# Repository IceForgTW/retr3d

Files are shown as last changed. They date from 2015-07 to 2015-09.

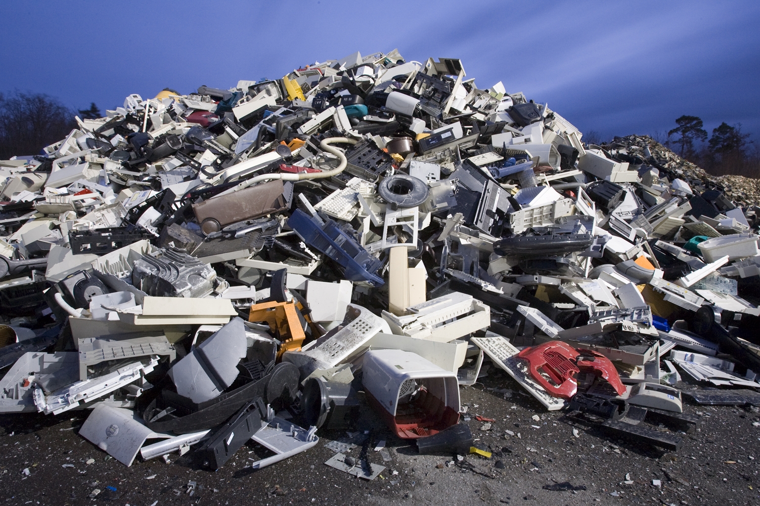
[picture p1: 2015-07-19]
img/ewaste.jpg

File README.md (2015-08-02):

## Notice
E-Waste 3D Printer is now **Retr3d**, pronounced just like "Retread." This change reflects the "Retreading" of 2D printers with a Z-Axis.
_____________

# Retr3d
In 2009, discarded TVs, computers, peripherals (including printers, scanners, fax machines) mice, keyboards, and cell phones totaled about 2.37 million short tons. Most of our e-waste ends up in landfills where toxic metals leach into the environment. This open source project aims to convert some of that e-waste into usable 3D printers. 
## Software
Retr3d uses python and FreeCAD to 3D model printable parts for the construction of more 3D printers. Through globalVars.py dimensions of procured e-waste are turned into customized 3D models. Retr3d's software depends on FreeCAD's python scripting API. FreeCAD can be found [here](http://www.freecadweb.org/wiki/index.php?title=Download "Download FreeCAD").
## Installation: Quick Version
Head over to our [latest release](https://github.com/masterperson40/retr3d/releases/latest) and download your appropriate file. Next, extract it. Hazzah! You're all done, now head over to <a href="#getting-started">Getting Started</a> to get on your way.

## Configuration
All of the customizable options can be configured [here.](https://cdn.rawgit.com/masterperson40/ewaste3Dprinter/master/config_generator/index.html) After generating your configuration file make sure to replace the original "globalVars.py file with the newly generated one.
## Getting Started
To begin creating a printer from the default options, open FreeCAD. Next, select from the menu.
Select "Macro > Macros ..."
<br />
Next, select the folder where is stored.
<br />
Click the "..." Button
Finally, select for the available options. After that, hit to create a printer.
Click makePrinter.py
<br />
If everything was installed correctly, you should now have something that looks like this:
printer
<br />
Remember, it might take a while for your printer to be modelled. Please be patient. 
## Plate
To facilitate an efficient work flow, Retr3d can interface with [Plater](https://github.com/RobotsWar/Plater) to arrange parts in an extremely efficient manner. Make sure to put the appropriate version of plater in the "plater" folder. (Eg. plater.exe, plater.app, or plater)

Plater
## Slic3r Integration
Retr3d can also interface with [Slic3r](https://github.com/alexrj/Slic3r) to slice parts automatically. After installing the dependencies, make sure to put the appropriate version of Slic3r in the "Slic3r" folder. (Eg. slic3r.exe, slic3r.app, or slic3r)

## Troubleshooting
#### AttributeError: 'module' object has no attribute 'getDocument'
This error is generated when running "makePrinter.py" directly from the command line. To fix, follow the instructions under "Getting Started" to run "makePrinter.py" as a FreeCAD macro.

#### raise Exception("getFace() error: No such face exists.")

Due to the way FreeCAD assigns faces in it's version 0.15, some users may have to downgrade to an earlier version. FreeCAD 0.14 Revision 2935 has been confirmed to work on a multitude of operating systems. Also, FreeCAD Version 0.16 Revision 5239 has also been confirmed to work.

To downgrade on Debian Linux:
```
sudo apt-get install freecad=0.13.2935-dfsg-1.1build1
```

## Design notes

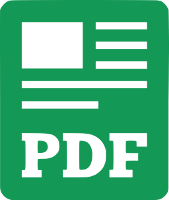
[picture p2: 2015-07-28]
img/pdf.png

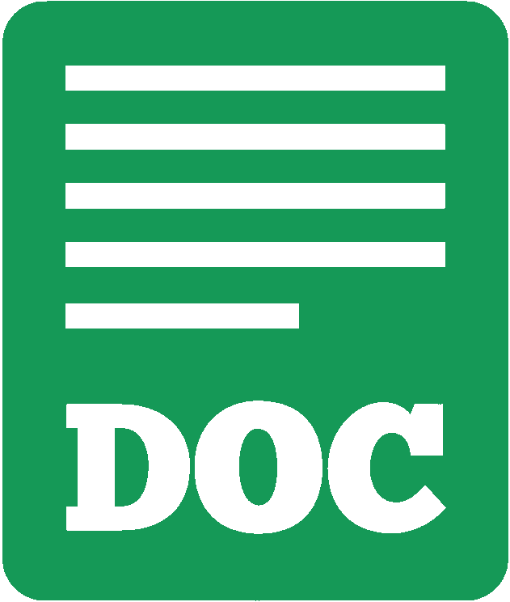
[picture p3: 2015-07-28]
img/doc.png

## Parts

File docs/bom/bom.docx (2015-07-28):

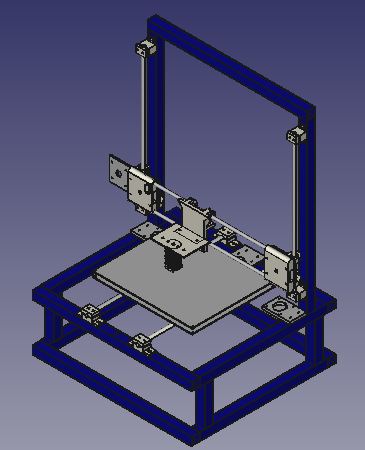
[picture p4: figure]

# Retr3d 3D Printer BOM updated 7/27/15

The materials needed to build the Retr3d 3D printer are divided into 3 categories: e-Waste components, printed parts, and purchased parts. Exact quantities of items like wire and steel tubing for the frame may vary, as all of the e-Waste printers are potentially unique.

E-Waste Components

See the E-Waste Harvesting notes for more information on how to identify, remove and group components that will work well for 3D printers. Be safe, e-waste can be dangerous!

Image | Item | Quantity | Source | Comments

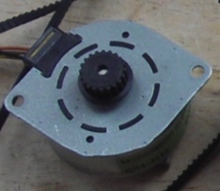
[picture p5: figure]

or | Stepper Motor, z-Axis | 2 | Paper printer, photocopier or scanner | The two motors must be the same. They can be either low-resolution “Tin Can” steppers or higher resolution hybrid steppers. No belt is needed for these motors. 4, 6,or 8 wire motors will work.
| Stepper Motor, x-Axis | 1 | Paper printer, photocopier or scanner | This must be a high-resolution hybrid stepper. If possible, it should be salvaged with a matching belt, pulley, and idler. 4, 6,or 8 wire motors will work.
| Stepper Motor, y-Axis | 1 | Paper printer, photocopier or scanner | This must be a high-resolution hybrid stepper. If possible, it should be salvaged with a matching belt, pulley, and idler. 4, 6,or 8 wire motors will work.
or | Stepper Motor, Extruder | 1 | Paper printer, photocopier or scanner | This can be either a “Tin Can” stepper or a Hybrid stepper motor. What is important is that it is sufficiently strong. 4, 6,or 8 wire motors will work.

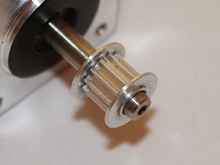
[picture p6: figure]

| Pulley, x-Axis | 1 | Paper printer, photocopier or scanner | Salvage with the motor, matching belt and idler if possible.
| Pulley, y-Axis | 1 | Paper printer, photocopier or scanner | Salvage with the motor, matching belt and idler if possible.
| Belt, x-Axis | 1 | Paper printer, photocopier or scanner | Salvage with the motor, matching pulley and idler if possible.
| Belt, y-Axis | 1 | Paper printer, photocopier or scanner | Salvage with the motor, matching pulley and idler if possible.
| Idler, x-Axis | 1 | Paper printer, photocopier or scanner | Salvage with the motor, matching pulley and belt if possible.
| Idler, x-Axis | 1 | Paper printer, photocopier or scanner | Salvage with the motor, matching pulley and belt if possible.

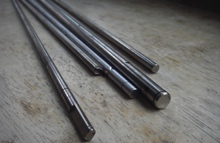
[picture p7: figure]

| Smooth Rods | 6 | Paper printer, photocopier or scanner | Diameter should be between 6 and 12mm. Length should be at least 200 mm. The entire length of the rod should be smooth and without grooves etc. except possibly the ends which can be cut off. If possible, salvage matching bushings from the same machine.
| Spring, Extruder | 2 | Paper printer, photocopier or scanner | Should be able to fit around a 3 or 4 mm diameter bolt. Approximately 20 mm long. Should be fairly stiff. The bolt in the image is shown for reference on how the spring should fit.
| Spring | 4 | Paper printer, photocopier or scanner | Should be able to fit around a 3 mm bolt. Approximately 20 mm long. Should be fairly stiff. The bolt in the image is shown for reference on how the spring should fit.

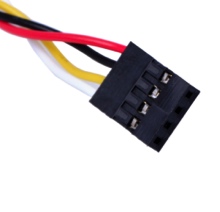
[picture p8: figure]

or | Wire Connectors, 4 position, for stepper motors | 5 | Paper printer, photocopier, scanner, computer | These must have a 2.54 mm pitch. Connectors with more than 4 positions can be used and cut to size if needed. Keep as much wire attached as possible.
or | Wire Connectors, 2 position, for endstops and thermistors | 5 | Paper printer, photocopier, scanner, computer | These must have a 2.54 mm pitch. Connectors with more than 2 positions can be used and cut to size if needed. Keep as much wire attached as possible. (Top image shows two connectors)

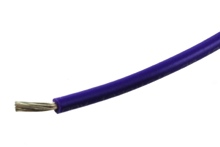
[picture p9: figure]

| Wire, approximately 18 AWG | 4 meters | Paper printer, photocopier, scanner, computer | For the heated bed and extruder resistor. This should be stranded wire. The wires on ATX power supplies work well and even wires taken from inside power cords. If it gets hot when it use, it isn’t large enough.
| Wire, 22 AWG or heavier | 8 meters | Paper printer, photocopier, scanner, computer | For hooking up the motors and fan. This should be stranded wire. It can be 22 AWG or heavier.
| Wire, 26 AWG approx.. | 5 meters | Paper printer, photocopier, scanner, computer | For the thermistors and endstops. This should be stranded wire. The fine wires used for sensors such as optical slot sensors, keypads etc. will work well. Heavier wire will also work.
| Power cord | 1 | Paper printer, photocopier, scanner, computer | Make sure it plugs into the power supply being used and that the plug fits the receptacles in the intended location for the printer.

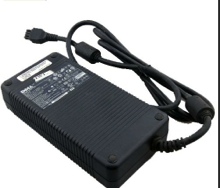
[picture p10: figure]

or | Power Supply | 1 or 2 | Computer or laptop | ATX power supplies as well as 12v power bricks work. 350 Watts or more is desirable though lower power can work. In terms of amperage delivered look for 12 or more. It may be possible to use 2 lower wattage power supplies may be used instead of one larger one.

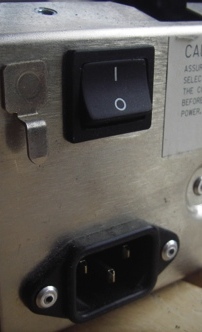
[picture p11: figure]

| Power cord plug and rocker switch (optional) | 1 | Paper printer, photocopier, scanner, computer | This is not absolutely necessary, but a highly recommended addition.
| USB cable | 1 | Paper printer, scanner, computer | USB 2.0 type cable with the ends shown in the photo.
| Small fan | 1 or 2 | Computer or laptop | This fan should measure 40mm on an edge or smaller.


| Magnet wire | 10 meters approx.. | Paper printer, scanner, computer | This wire can be taken from a servomotor, stepper motor or transformer. If possible don’t take it from a working stepper motor. It should be approximately 26 AWG and have a diameter between 0.35 and 0.45 mm. The particulars vary depending on the size of the print bed.

# Other e-Waste components that may be useful, depending on who is building the printers

Image | Item | Quantity | Source | Comments
| Optical Endstops | 3 | Paper printer, scanner, photocopier | These may have 3 or 4 wires and should operate on 5 v. The main issues are attaching them to the printers properly and wiring.
| Mechanical endstops | 3 | Paper printer, scanner, photocopier | These should work just fine for a 3D printer, It is just a matter of adjusting the design so they can be attached properly.


| Brass Bushings | Up to 12 or 2 per smooth rod | Paper printer or scanner | If present, these should always be salvaged with the smooth rod.

3D Printed Parts

Keep in mind that your parts might look slightly different as their designs are modified to fit with the other parts of the printer. All of these parts should be printed with at least 2 shells and 50% infill.

Image | Item | Quantity | Notes
| PrintBedBushingHolderL | 2 | Print Lying down with nut trap facing upwards.
| PrintBedBushingHolderL | 2 | Print Lying down with nut trap facing upwards.


| xCarriage | 1 | Print with large flat face facing downward.
| xEndZRodHolderL | 1 | Print with large flat face facing downward.
| xEndZRodHolderR | 1 | Print with large flat face facing downward.


| yBeltAnchor | 1 | Print standing up as shown.
| yMotorMount | 1 | Print as shown.
| xRodClampL | 1 | Print standing up with x-Rod holes pointing upwards.


| xRodClampR | 1 | Print standing up with x-Rod holes pointing upwards.
| yRodSupportL | 2 | Print as shown.
| yRodSupportLClamp | 2 | Print as shown.
| yRodSupportR | 2 | Print as shown.
| yRodSupportRClamp | 2 | Print as shown.


| zMotorMount | 2 | Print as shown.
| zRodSupportL | 2 | Print as shown.
| zRodSupportLClamp | 2 | Print as shown.
| zRodSupportR | 2 | Print as shown.
| zRodSupportRClamp | 2 | Print as shown.
| Feet | 4 | Print as shown.


| Extruder Body | 1 | Print lying down. Image shown is nearly a top view for printing.
| Extruder pinion | 1 | Print as shown.
| Extruder gear | 1 | Print as shown.


| Guidler | 1 | Print as shown.
| Fan Shroud | 1 | Print as shown with support.
| Arduino standoffs | 4 | Print as shown.

# Purchased Parts

The following parts usually need to be purchased and sometimes imported. Some of the items are purchased as raw materials and then worked into their final shape. See the notes on Purchasing Parts for information on where to purchase parts and what to look for. The bolts will vary in length depending on the design generated. Purchase after doing the design work to avoid problems. Prices are estimated in USD and may vary greatly based on supplier, shipping costs and import duties. The total cost estimate is $82.

Image | Item(s) | Quantity | Price | Total | Notes
| 1 Bolt 1 Nut 2 Washers | 16 | 0.05 | 0.8 | For mounting rod supports. These can be hex head, pan head or socket. 3 or 4 mm diameter usually works well. If making a wooden frame, these will be wood screws with one washer each.
| 1 Bolt 1 Nut 2Washers | 6 | 0.07 | 0.42 | For mounting the motor mounts. These can be hex head, pan head or socket. 3 or 4 mm diameter usually works well. If making a wooden frame, these will be wood screws with one washer each.


| 1Bolt 1Nut 1Washer | 16 | 0.06 | 0.96 | For joining the clamps to the rod supports. These can be hex head, pan head or socket. 3 or 4 mm diameter usually works well.
| Bolt | 20 | 0.04 | 0.80 | For mounting stepper motors. They must match the motors so sizes/lengths may vary (frequently 3mm dia). “Tin can” motors will only require two mounting bolts instead of 4.
| 1 Bolt 1 Nut 2Washers | 8 | 0.07 | 0.56 | For bolting the xEnd parts together. Depending on how the x endstop is mounted, one of these may need to be longer than the rest. These can be hex head, pan head or socket. Check the printer design before purchasing.
| 1 Bolt 1 Nut 2Washers | 8 | 0.07 | 0.56 | For bolting the bushing holders onto the print bed support. These can be hex head, pan head or socket. Check the printer design before purchasing.
| 1 Bolt 1 Nut 2Washers | 4 | 0.07 | 0.28 | For bolting the Arduino mounting plate to the frame. 3mm or something similar will work. These can be hex head, pan head or socket.
| 1 Bolt 1 Nut 2Washers | 4 | 0.07 | 0.28 | For bolting the printed feet to the frame. 3mm or something similar will work. These can be pan head or socket.


| 1 Bolt 1 Nut | 4 | 0.05 | 0.20 | For bolting the print bed onto the print bed support. 3mm bolts 20 mm long work well though other diameters will also work. These can be hex head, pan head or socket.
| 1 Bolt 1 Nut 1Washer | 4 | 0.06 | 0.24 | For mounting the extruder mount plate and extruder mount angle to the xCarriage. 3mm is standard but other similar diameters will work.
| 1 Bolt 1 Nut 1Washer | 2 | 0.06 | 0.12 | For mounting the geared extruder to the extruder mounting plate. 4mm is standard, but 3mm or something similar will also work. These can be hex head, pan head or socket.
| Bolt | 2 | 0.4 | 0.08 | For mounting the hotend to the extruder mount plate. These can be hex head, pan head or socket. 3mm is standard but other similar diameters can be used.


| Brass Nut | 11 | 0.35 | 3.85 | For bushings. Sizes depend on diameters of the smooth rods and available brass nut sizes. Check the printer design before purchasing.
| 1 Bolt 1 Nut 3 Washers | 1 | 0.10 | 0.10 | For mounting the y-Axis idler. Must be sized to match the diameter of the y-Axis idler.
| 1 Bolt 1 Nut 5 Washers | 1 | 0.10 | 0.10 | For mounting the x-Axis idler. Must be sized to match the diameter of the x-Axis idler. Use the extra washers to fill the space between the idler and the parts it mounts to.


| Threaded Rod 2 Nuts | 1 meter | 2.10 | 2.10 | For the two z-Axis lead screws. 5mm works well though other diameters can also be used. The exact length will be determined by the printer design so check before purchasing.
| Vinyl tubing | 10 cm | 0.50 | 0.50 | For attaching lead screws to z-Axis motors. The size depends on the diameter of the lead screws and the motor shaft or pinion.
| 50mm wide Kapton tape | 160 cm | 0.40 | 0.40 | For attaching the resistor wire to the bottom of the heated bed.


| 100K EPCOS thermistor | 2 | .90 | 1.80 | For heated bed and extruder temperature sensing.
| 5.6 Ohm resistor | 1 | 0.78 | 0.78 | For heating the nozzle. Use 5 watt power resistors. Make sure that the fit snugly into the heater block on the extruder.
| Teflon tubing, 5/16” dia | 5 cm | 0.16 | 0.16 | For insulating the heater resistor leads.
| Teflon tubing, 3/32” dia | 10 cm | 0.16 | 0.16 | For insulating the thermistor leads on the hotend and heated bed.
| Extruder Barrel | 1 | 0.65 | 0.65 | Made from 25mm diameter Aluminum rod.
| Teflon Tubing, 1/4 in OD, 1/8 in ID | 60mm | 0.65 | 0.65 | For lining the extruder barrel.
| Extruder Nozzle and heater block | 1 | 0.16 | 0.16 | Made from 13x19mm aluminum bar.
| Bolt | 2 | 0.05 | 0.10 | For attaching heater block to barrel.
| 1 Bolt 1 Washer | 1 | 0.05 | 0.05 | For retaining the thermistor.
| Stainless steel spacers | 3 | 0.05 | 0.15 | For separating the heater block from the barrel. Made from stainless steel sheet metal. Normal steel will work if stainless is unavailable.
| Engine gasket spacers | 4 | 0.02 | 0.08 | For separating the heater block from the barrel. Made from fiber gasket material
| Nozzle harness | 1 | 0.05 | 0.05 | For holding the nozzle onto the barrel. Made from stainless steel sheet metal. Normal steel will work if stainless is unavailable.
| 1 Bolt, 8mm dia 60 mm long 1 lock nut 5 washers | 1 | 0.60 | 0.60 | For making the hobbed bolt for the extruder.
| 1 Bolt, 60 mm long 1 nut 2 washers | 2 | 0.40 | 0.80 | For extruder. These are the bolts that clamp the filament against the hobbed bolt.
| 1 Bolt 1 Nut | 1 | 0.06 | 0.06 | For attaching guidler to the extruder body. Normally 3mm.


| 8mm rod, 20 mm long | 1 | 0.05 | 0.05 | Shaft for the guidler bearing. Can be cut from an 8mm bolt or rod. Threaded or smooth.
| 608zz ball bearing | 3 | 0.75 | 2.25 | For the extruder body.
| Heat Shrink | 25 cm | 0.75 | 0.75 | For insulating soldered joints in the electronics. Two different sizes may be useful. One for fine wires like 22 AWG and another for larger 18 AWG wires.


| Arduino mega 2560 | 1 | 17.00 | 17.00 | This must be an Arduino mega 2560.
| Ramps 1.4 | 1 | 13.00 | 13.00 | This is the interface between the Arduino and the rest of the printer.
| Pololu A9488 Stepper driver | 4 | 2.00 | 8.00 | These or compatible stepper drivers are needed to drive the stepper motors.


| SD card reader | 1 | 2.88 | 2.88 | Optional. Enables printer to be used without a computer.
| Aluminum plate, 200x200x1.5 mm | 2 | 6.50 | 13.00 | For the print bed and the print bed support. This aluminum plate must be very flat. Dimensions will vary depending on the printer design.
| Aluminum Bar, 50x80x3 mm | 1 | 0.32 | 0.32 | For the x-Axis motor mount.
| Square Tubing, 20x20 mm | 6 meters | 4.50 | 4.50 | For the printer frame. Can be fairly lightweight. Larger sizes will also work.
| Zip ties | 1 pack | 1.00 | 1.00 | For cable management.

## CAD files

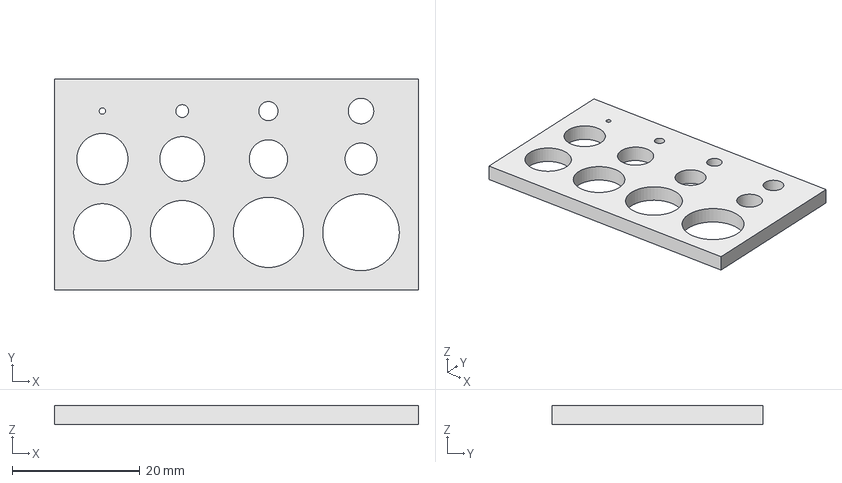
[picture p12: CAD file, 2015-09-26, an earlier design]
old/HolePattern.FCStd
57.0 x 33.0 x 3.00 mm

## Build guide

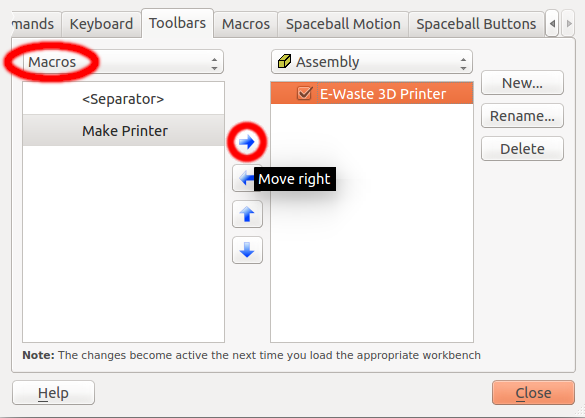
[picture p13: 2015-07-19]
docs/macro/step4.png

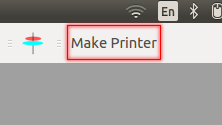
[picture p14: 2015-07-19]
docs/macro/step5.png

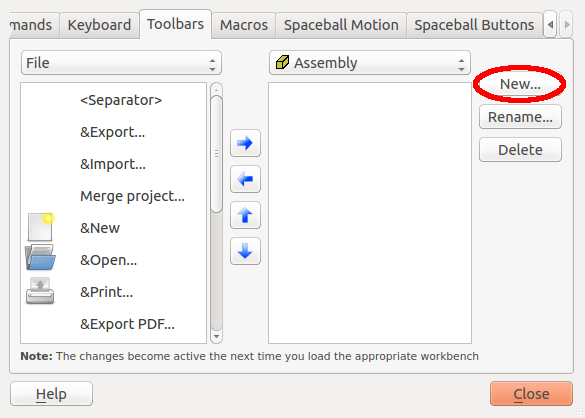
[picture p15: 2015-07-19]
docs/macro/step2.png

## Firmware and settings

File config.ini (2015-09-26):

[File Paths]
freecad directory = C:\Program Files (x86)\FreeCAD 0.15\bin
printer files directory = C:\Users\Public\Documents\Printers\

[xRodBottom]
length_of_shorter_x_rod = 400
diameter = 8

[xRodLeft]
diameter = 8

[xRodTop]
length_of_shorter_x_rod = 400
diameter = 8

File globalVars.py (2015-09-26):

# Copyright 2015 Matthew Rogge and Michael Uttmark
# 
# This file is part of Retr3d.
# 
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
from __future__ import division # allows floating point division from integersimport math

reloadClasses = False
test = None

#Change the following to the path to the directory that will hold your printer designs
#Unless using windows, then use \\ instead of either of the above
#Make sure to use forward slashes like this / and not back slashes like this \ 
freecadDir = "C:\\Program Files (x86)\\FreeCAD 0.15\\bin"
printerDir = "/Path/To/Store/3D/Files/"
 
#Output Options
level = 2

#make test hole pattern. True if you would like the test hole pattern to be included in your stl files
printTestHolePattern = True
 
#xRod vars
xRodDiaTop = 7.9 #Diameter of the top xRod
xRodDiaBottom = 7.9 #Diameter of the bottom xRod
xRodLength = 400 # Length of the shorter xRod
xRodDiaMax = None 					#CALCULATED The largest xRod diameter
xMotorShaftToMountHoleDistX = None 	#CALCULATED The horizontal component of the distance between the shaft and the mounting holes
xMotorBodyWidth = None 				#CALCULATED Width of the xMotors body
xRodSpacing = None 					#CALCULATED The distance between the axes of the xRods. 
 
#yRod vars
yRodDiaL = 12.7 #Diameter of the top yRod
yRodDiaR = 12.7 #Diameter of the bottom yRod
yRodLength = 460 # Length of the shorter yRod
yRodSpacing = None	#CALCULATED Distance between yRods
yRodDiaMax = None 	#CALCULATED largest yRod diameter
yBushingNutMaxThickness = None #Calculated The maximum thickness of the y bushing nuts
                                                                                            
#zRod vars                                                                                  
zRodDiaR = 12.7 #Diameter of the right zRod                                                   
zRodDiaL = 12.7 #Diameter of the left zRod                                                 
zRodLength = 460 #Length of the shorter zRod                                                
zRodSpacing = None	#CALCULATED Distance between zRod axes                               
zRodStandoff = None	#CALCULATED Distance between frame surface and zRod Axis             
 
#Lead Screw Related                                                                                                                                                        
leadScrewDia = 6.35 #Diameter of the leadScrew                                                                                                                             
zRodZScrewDist = None #CALCULATED Distance between the axis of the zRod and the axis of the LeadScrew. Increased if needed                                                 
                                                                                                                                                                           
                                                                                                                                                                           
#Frame vars                                                                                                                                                                
frameWidth = 20 #Width of frame members on the face to which the y and z axes are attached.                                                                                
frameHeight = 19.05#Height of frame members. This is the 2nd cross sectional dimension                                                                                    
frameThickness = 1.33 #Thickness of frame wall if frame is hollow.                                                                                                         
frameJointPadding = 10 #ADVANCED Required distance at frame joints for welds which might get in the way of mounted parts                                                   
                                                                                                                                                                           
                                                                                                                                                                           
#Mounting nut and bolt info                                                                                                                                                
mountToPrintedDia = 3 #Actual diameter of holes that are used to mount items to printed parts. IE other printed parts or sheet metal.                                      
mountToFrameDia = 4.12 #Actual diameter of holes that are used to mount items to the frame. Printed parts to frame or sheet metal to frame.                                
mountToFrameHeadDia = 6         #Actual head diameter of bolts used to mount items to the frame.
mountToFrameHeadThickness = 3   #Actual head Thickness of bolts used to mount items to the frame.
mountToPrintedPadding = 3	#ADVANCED the minimum distance between the edge of a hole and the edge of the part                                                          
printedToFrameDia = None 	#CALCULATED The adjusted diameter for printed parts that will be mounted to the frame.                                                      
printedToFrameHeadDia = None    #CALCULATED The adjusted diameter for printed parts that will be mounted to the frame.                                                     
printedToPrintedDia = None 	#CALCULATED The adjusted diameter for printed parts mounted to other printed parts or to non frame parts                                    
                                                                                                                                                                           
                                                                                                                                                                           
#rodClamps - much of this should be combined with mounting bolt info above                                                                                                 
clampHoleDia = 3.5 				#ADVANCED Diameter of clamping holes on rod clamps and endStop mounts                                                       
clampNutPadding = 3 			#ADVANCED The minimum wall thickness for the clamp nut cut out                                                                      
clampNutFaceToFace = 5.6 		#ADVANCED Face to face distance of clamp nuts                                                                                       
clampNutThickness = 2.5 		#ADVANCED The thickness of the clamp nuts                                                                                           
clampGap = 2 					#ADVANCED The gap between the support and the clamp
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

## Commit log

2015-07-28 Added BOM
2015-07-28 Added links to BOM and soon to be License page
2015-07-28 Updated style for BOM and new docs page
2015-08-21 Added Marlin.py
2015-08-22 Integrated Marlin
2015-09-26 Initial commit for retr3dv0.2.0
    This adds the basis for 0.2.0 with modularity and MVC basis, however, it is not a fully working version of the code, and is in very early development.
    [HolePattern.FCStd, decoy.xlsx]
2015-09-26 Inital commit, take two
    [HolePattern.FCStd]
2015-09-26 Clarified structure; Added Utilities
    Retr3d v0.2.0 can now save files, and sort them (better). Moreover, the model has been corrected, and the printer now "has" parts rather then before when it "was" a part.

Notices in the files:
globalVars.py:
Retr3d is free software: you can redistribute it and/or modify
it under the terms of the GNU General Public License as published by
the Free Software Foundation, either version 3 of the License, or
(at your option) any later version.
